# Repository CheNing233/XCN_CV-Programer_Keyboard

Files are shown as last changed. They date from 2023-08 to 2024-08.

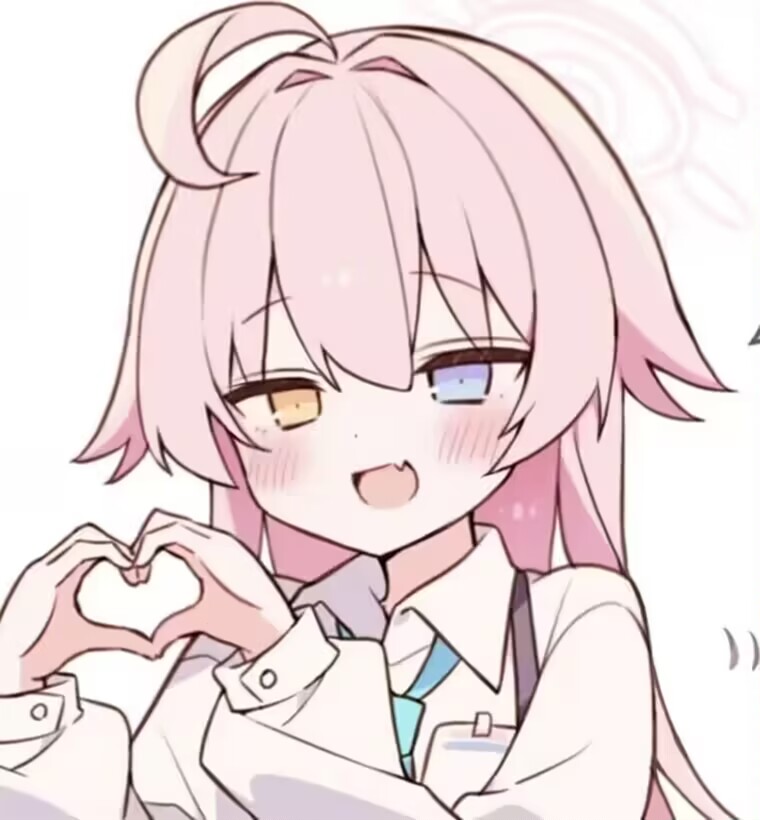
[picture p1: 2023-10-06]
HDK/PCB/QQ图片20231001015254.jpg

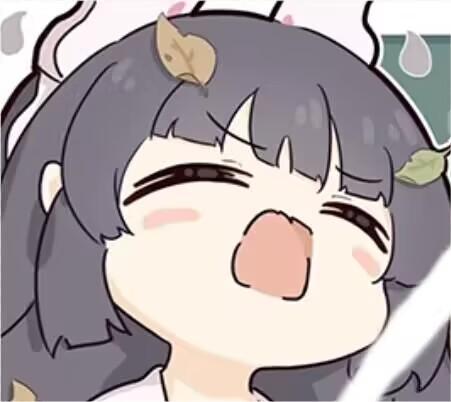
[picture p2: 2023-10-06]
HDK/PCB/QQ图片20231001020005.jpg

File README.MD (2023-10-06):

# XCN CV-Programer Keyboard (USB+BLE)

Dual mode 8-key keyboard based on CH573 microcontroller, Using an on chip integrated BLE wireless communication module and USB controller

一个`菜鸡`大学生的学习项目

## Feature

- [x] X, C, V, Space, Ctrl键
- [x] 旋转编码器(Encoder)设计的音量(Vol)滚轮以及播放暂停(Play/Pause)键
- [x] USB/BLE模式切换开关
- [ ] 光污染

## Progress & Tips

- [x] USB
- [x] BLE
- [x] Key scan
- [x] PCB
- [x] Casing CAD
- [ ] Macro
- [ ] ...

尝试使用补偿来解决BLE上传Encoder关于 “丢失数据” 的问题

## Thanks

- WCH南京沁恒
- You

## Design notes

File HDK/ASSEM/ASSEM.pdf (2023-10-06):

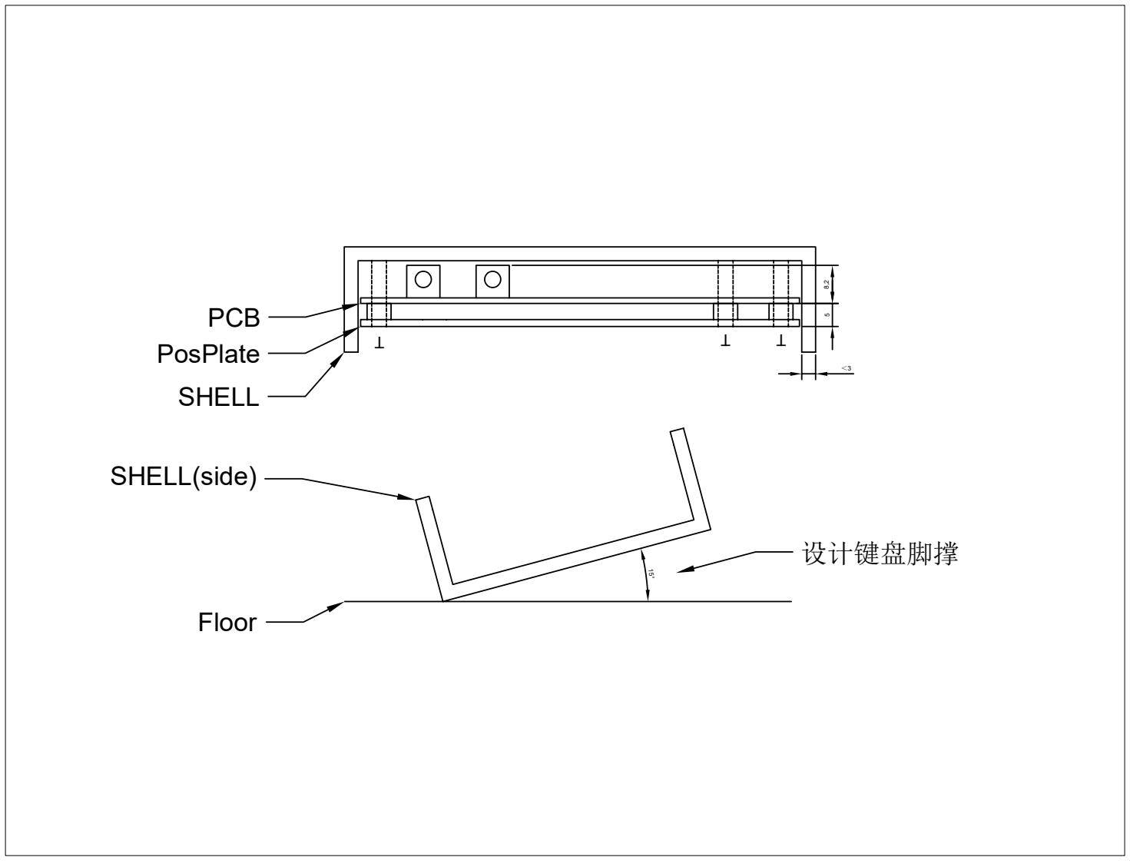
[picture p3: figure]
PCB PosPlate SHELL; T 15°Floor SHELL(side); 设计键盘脚撑

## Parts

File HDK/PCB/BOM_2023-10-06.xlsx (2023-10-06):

Designator | Value | Footprint | Device
C1 | 1uf | C0805 | CAP_0805 | 电容
C2 | 4.7uf | C0805 | CAP_0805
C3,C4,C5,C6 | 100nF | C0603 | CAP_0603
C7 | 0.1uf | C0805 | CAP_0805
D1 |  | SMA_L4.3-W2.6-LS5.2-RD | SS24_C50645 | 肖特基二极管
D2 |  | LL-34_L3.5-W1.5-RD | ZMM5V1_C707194 | 稳压二极管
H1,H2 |  | HDR-TH_2P-P2.54-V-F | HDR-F_2.54_1x2P
KEY1,KEY2,KEY3,KEY4,KEY5 |  | AxisSeat_14_18_XCN1 | CPG151101S11 | 轴座
L1 |  | ANT2051 | AN2051-245 | 陶瓷天线
LED1,LED2 |  | LED_0805 | LED_0805-G,LED_0805-R | 0805充电指示灯
M1 |  | VIBRATING-MOTOR-SMD_3P-C9900001680 | Z3OC1T8219731 | 振动电机
Q1,Q3 |  | SOT-23-3_L2.9-W1.3-P1.90-LS2.4-BR | FMMT718_C5277995 | FMMT低阻pnp三极管
Q2,Q4 |  | SOT-23-3_L2.9-W1.4-P1.90-LS2.6-BR | AO3401_C727156 | AO3401p沟道pmos
R1 | 2.2K | R0805 | Res_0805 | 电阻
R2,R9,R10,R12 | 10K | R0805 | Res_0805
R3 | 1K | R0805 | Res_0805
R4 | 100K | R0805 | Res_0805
R5,R6 | 5.1K | R0805 | Res_0805
R7 | 6.8K | R0805 | Res_0805
R8,R11 | 0K | R0805 | Res_0805
R13 | 2.4K | R0805 | Res_0805
SW1,SW6 |  | SW-TH_SK12D07VG3 | SK12D07VG3 | 拨动开关
SW2 |  | SW-SMD_L3.9-W3.0-P4.45 | TS-1088R-02026 | RST龟仔
SW3 |  | SW-TH_EC11XXXXXXXX | EC11E18244AU | EC11编码器
SW7,SW8 |  | KEY-TH_4P-L7.1-W5.0-P4.50-LS2.5 | TS-1093A-A3B2-D2 | 侧按钮
U1 |  | SOT-23-5_L3.0-W1.7-P0.95-LS2.8-BL | RT9013-33GB | LDO稳压
U2,U3,U4,U6,U7,U8 |  | LED-SMD_L3.2-W2.8-TR | SK6812MINI-E_C5149201 | 6812RGB灯珠
U5 |  | ESOP-8_L4.9-W3.9-P1.27-LS6.0-BL-EP | TP4056_C725790 | TP4056电池充电芯片
U9 |  | QFN-28_L4.0-W4.0-P0.40-BL-EP | CH573F | MCU
USB1 |  | USB-C-SMD_KH-TYPE-C-16P | KH-TYPE-C-16P-T | TYPEC
X1 | 32.768kHz | OSC-SMD_L3.2-W1.5 | X321532768KGD2SI | 32K时钟晶振
X2 | 32MHz | OSC-SMD_4P-L2.0-W1.6-BL | X201632MMB4SI | 32M主频晶振

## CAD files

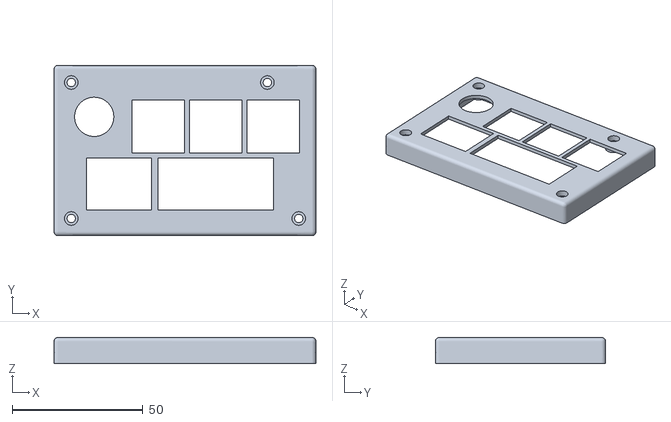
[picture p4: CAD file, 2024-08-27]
HDK/CASING/CasingUpper.stl
100.2 x 65.2 x 10.0

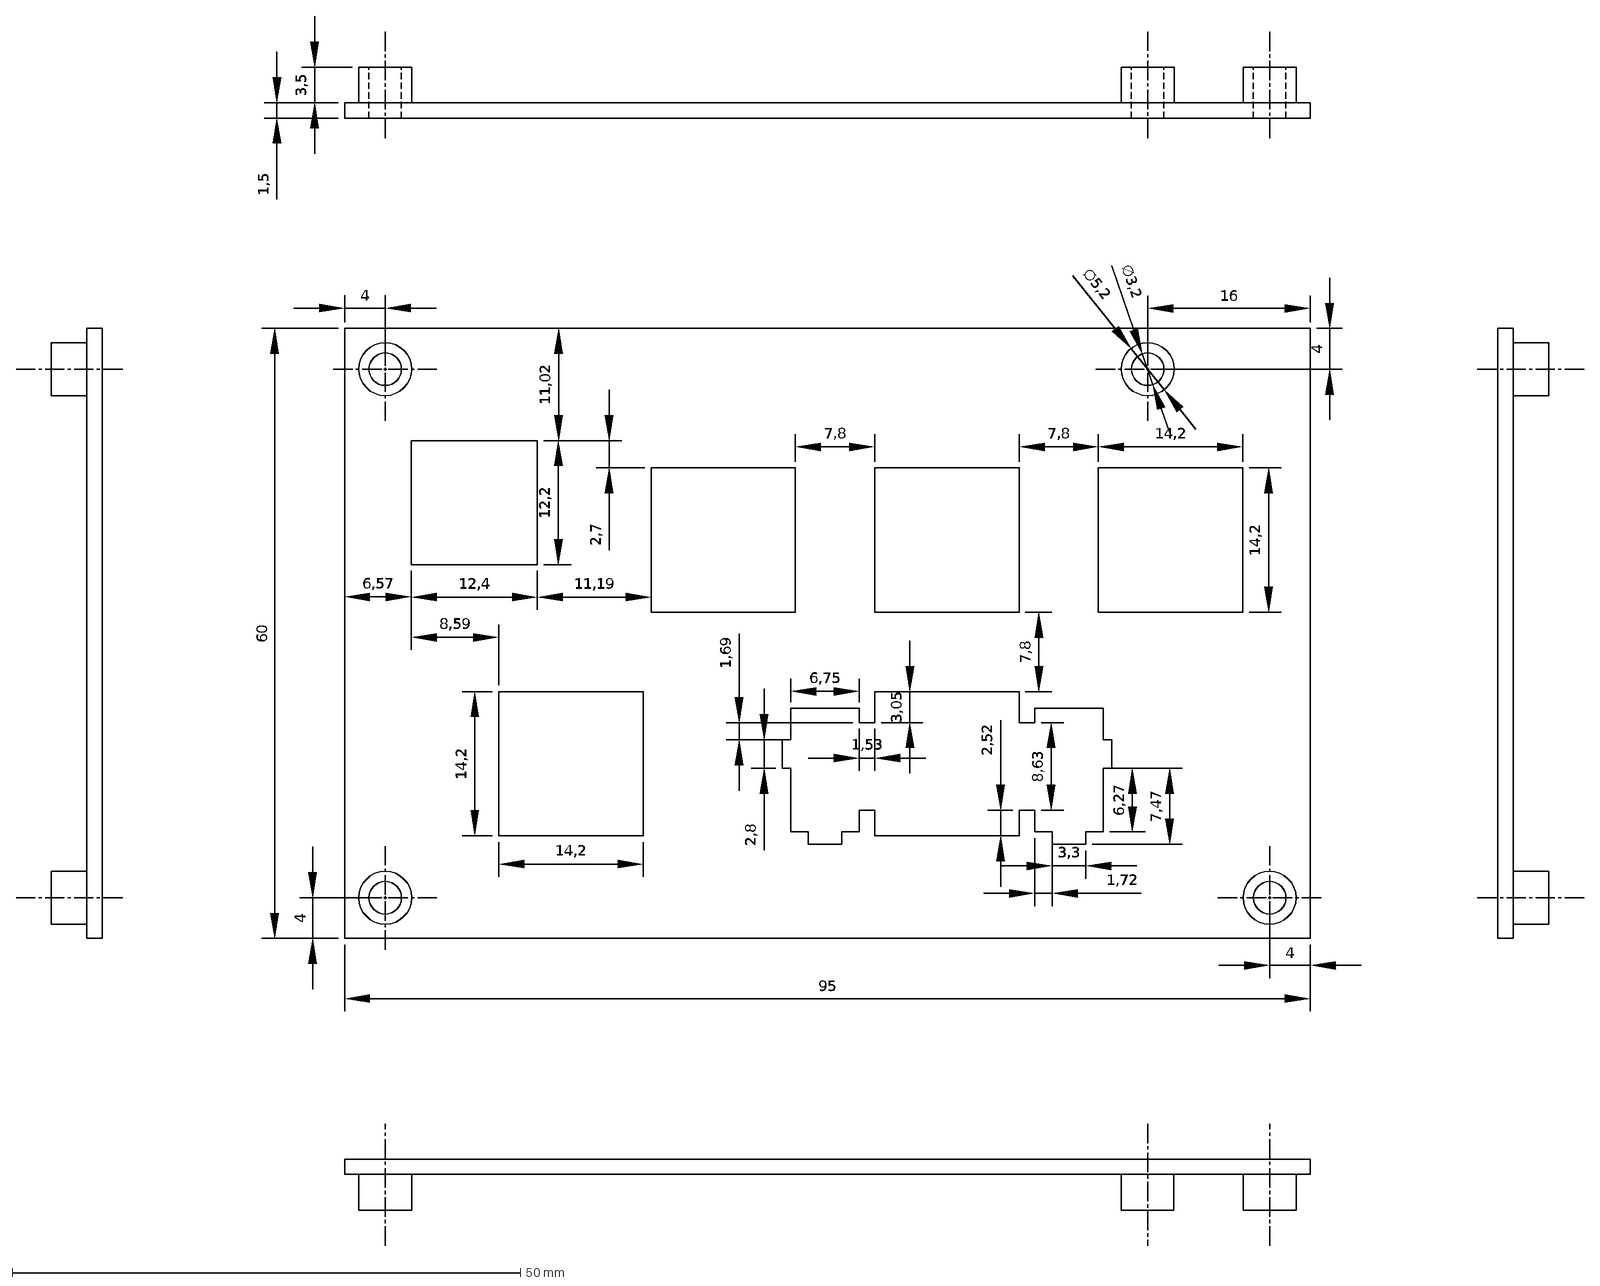
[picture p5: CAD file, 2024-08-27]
HDK/POS_PLATE/PosPlate.dxf
60
95
4
16
14,2
∅3,2
∅5,2
11,02
12,2
6,57
12,4
8,59
11,19
3,05
1,53
1,69
2,8
6,75
2,52
1,72
3,3
7,47
6,27
2,7
7,8
8,63
1,5
3,5

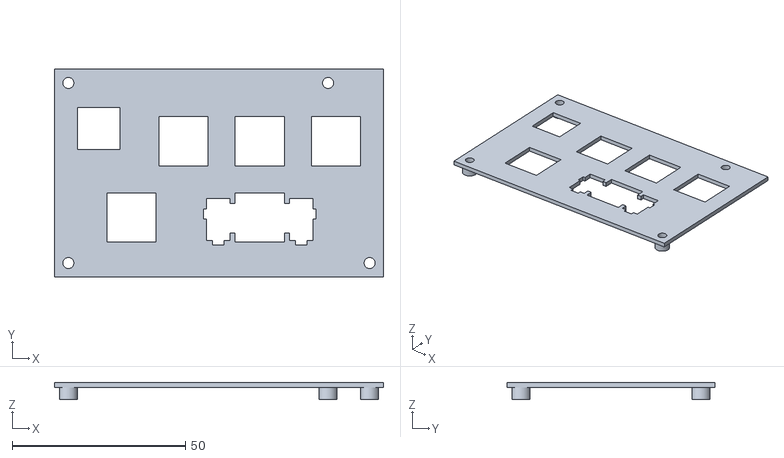
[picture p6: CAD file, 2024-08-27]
HDK/CASING/PosPlate.stl
95.0 x 60.0 x 5.00

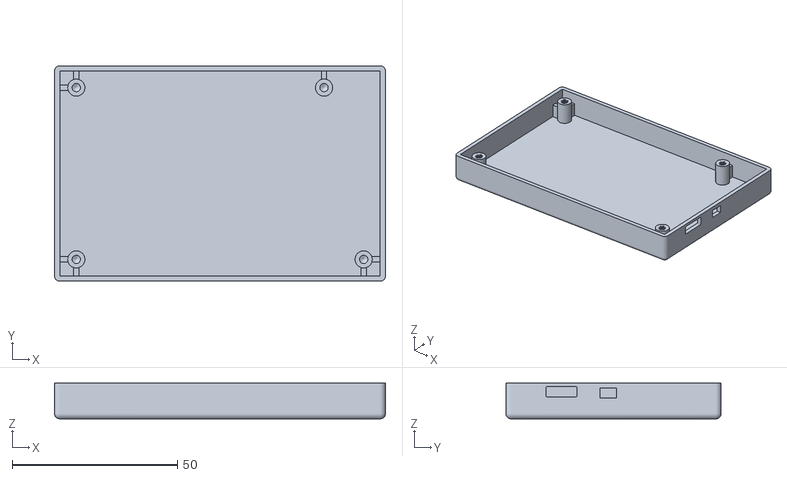
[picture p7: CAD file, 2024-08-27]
HDK/CASING/CasingBottom.stl
100.2 x 65.2 x 10.8

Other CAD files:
HDK/ASSEM/ASSEM.dwg
HDK/CASING_REF/CASING_REF.dwg
HDK/POS_PLATE/PosPlate_o.dwg
HDK/CASING/CASING_CAD.dxf
HDK/POS_PLATE/DMKB_01 v4.dwg
HDK/CASING/DMKB_02 v20.dwg
HDK/CASING/CASING_CAD.dwg
HDK/POS_PLATE/PosPlate.dwg

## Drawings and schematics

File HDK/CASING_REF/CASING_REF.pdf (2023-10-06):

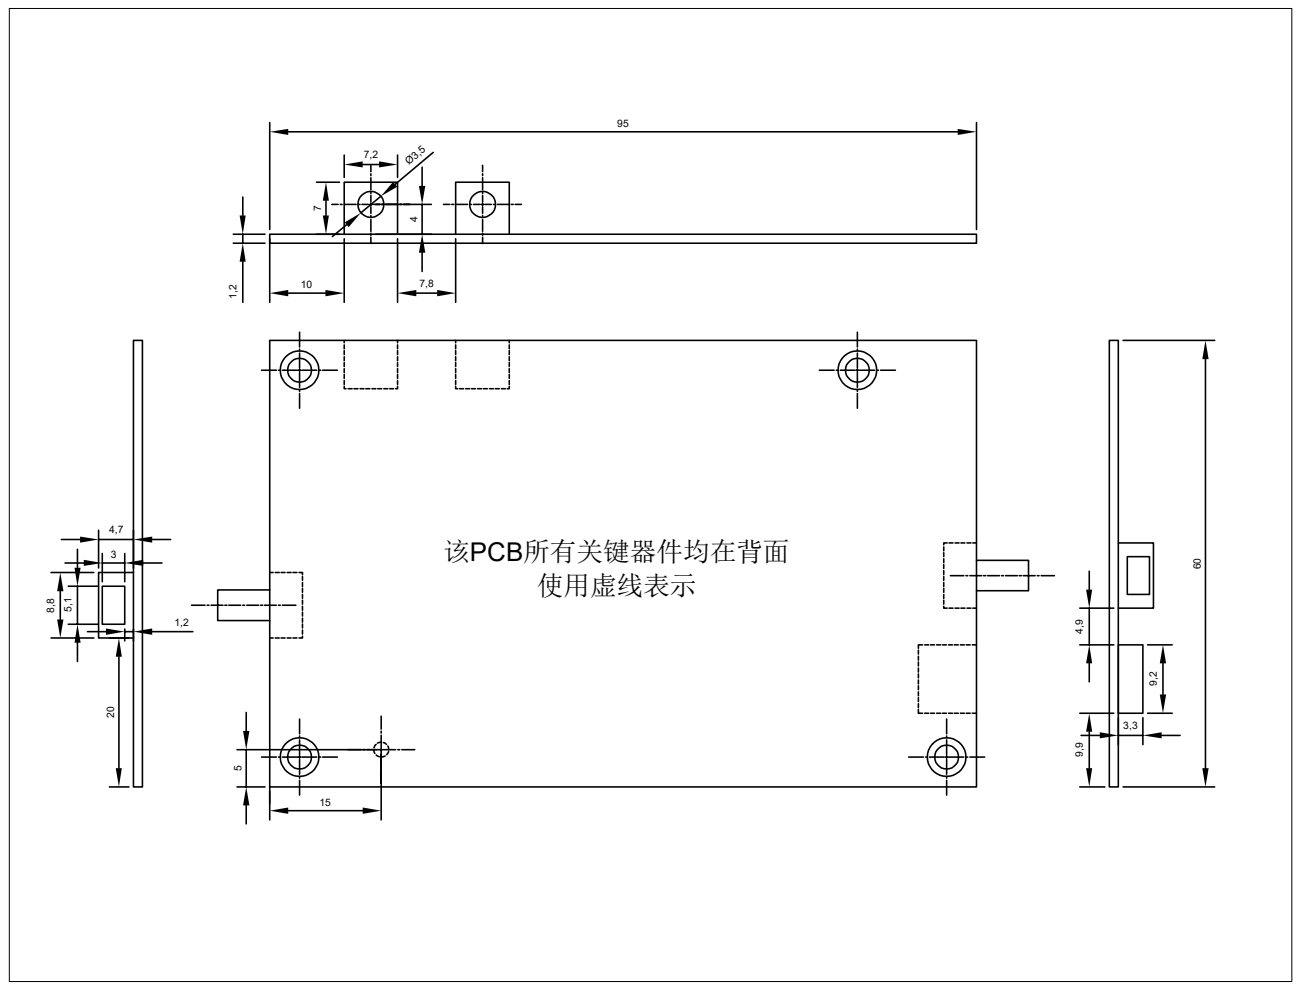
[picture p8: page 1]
该PCB所有关键器件均在背面 使用虚线表示 15 ⁵

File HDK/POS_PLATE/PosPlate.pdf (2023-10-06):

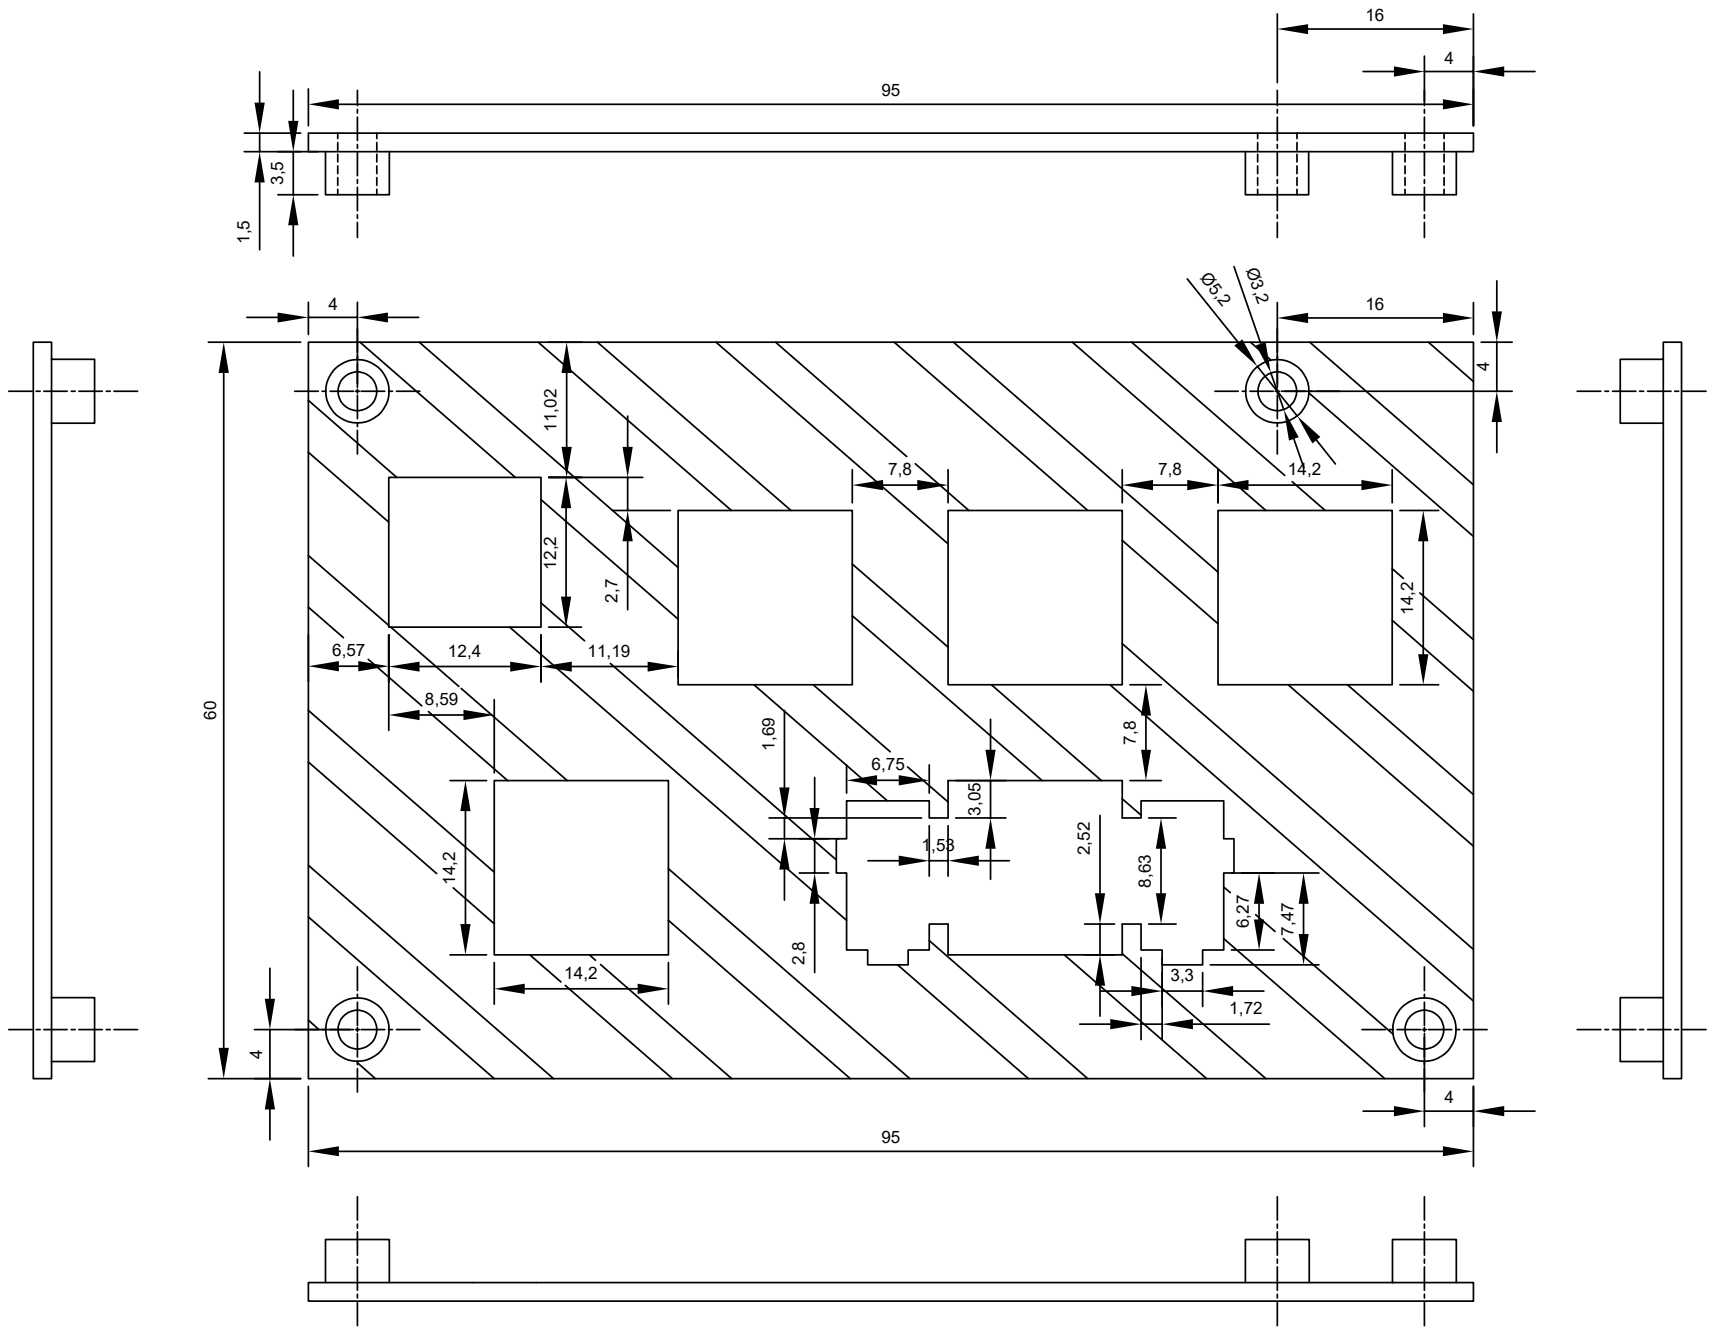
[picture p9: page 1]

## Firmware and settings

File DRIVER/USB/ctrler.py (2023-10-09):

import os
import logging
from array import array

import usb.core
import usb.util
import usb.backend.libusb1


class USB_Controller:
    pyusb_backend_path = ""
    pyusb_backend = None

    pyusb_device: usb.core.Device = None

    xcnkb_idVendor = 0x413D
    xcnkb_idProduct = 0x2107

    xcnkb_bulkin_addr = 0x83
    xcnkb_bulkout_addr = 0x4

    def __init__(self) -> None:
        self.pyusb_backend_path = os.path.join(
            os.path.dirname(os.path.abspath(__file__)), "libusb-1.0.dll"
        )

        self.pyusb_backend = usb.backend.libusb1.get_backend(
            find_library=lambda x: self.pyusb_backend_path
        )

        logging.info("pyusb.backend = %s" % (self.pyusb_backend))

    def get_target_device(self) -> int | None:
        self.pyusb_device = usb.core.find(
            idVendor=self.xcnkb_idVendor,
            idProduct=self.xcnkb_idProduct,
            backend=self.pyusb_backend,
        )

        if self.pyusb_device == None:
            logging.error("目标设备查找失败")
            return None

        # logging.debug("Target device info:\n%s" % (self.pyusb_device))

        self.pyusb_device.set_configuration()

        return self.pyusb_device.get_active_configuration()

    def check_valid(self) -> list | None:
        if self.pyusb_device == None:
            logging.error("设备句柄为空，停止该操作")
            return None

        msg = array("B")
        msg.append(0)

        logging.info("MSG = %s" % (msg))

        self.pyusb_device.write(self.xcnkb_bulkout_addr, msg, 3000)

        response = None

        try:
            response = self.pyusb_device.read(self.xcnkb_bulkin_addr, 64, 3000)
        except:
            logging.error("self.pyusb_device.read 失败")
            return None

        if not response[0] == 233:
            logging.error("self.pyusb_device.read 下位机响应异常")
            return None

        logging.info("MSG = %s" % (response))

        return [response[1], response[2], response[3]]

    def write(self, cmd_key, msg_data: array = None) -> array:
        if self.check_valid() == None:
            logging.error("操作取消")
            return None

        msg = array("B")
        msg.append(cmd_key)

        if msg_data:
            msg += msg_data
            logging.info(
                "即将向 0x%x 发送 %d 请求，附加数据 = %s"
                % (self.xcnkb_bulkout_addr, cmd_key, msg_data),
            )

        try:
            self.pyusb_device.write(self.xcnkb_bulkout_addr, msg, 3000)
        except:
            logging.error("self.pyusb_device.write 失败")
            return None

        logging.info("成功向 0x%x 发送 %d 请求" % (self.xcnkb_bulkout_addr, cmd_key))

        try:
            response = self.pyusb_device.read(self.xcnkb_bulkin_addr, 64, 3000)
        except:
            logging.error("self.pyusb_device.read 失败")
            return None

        logging.info("0x%x 返回 = %s" % (self.xcnkb_bulkin_addr, response))

        return response


if __name__ == "__main__":
    logging.basicConfig(
        format="[%(asctime)s|%(levelname)s] %(funcName)s : %(message)s",
        level=logging.DEBUG,
    )

    logging.info("LOG OK")

    ctrler = USB_Controller()

    ctrler.get_target_device()

    print(ctrler.check_valid())

    # print(pyu.pyusb_device.product)
    # print(type(pyu.pyusb_device))
    # print(pyu.pyusb_device.get_active_configuration())

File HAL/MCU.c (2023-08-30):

/********************************** (C) COPYRIGHT *******************************
 * File Name          : MCU.c
 * Author             : WCH
 * Version            : V1.2
 * Date               : 2022/01/18
 * Description        : 硬件任务处理函数及BLE和硬件初始化
 *********************************************************************************
 * Copyright (c) 2021 Nanjing Qinheng Microelectronics Co., Ltd.
 * Attention: This software (modified or not) and binary are used for 
 * microcontroller manufactured by Nanjing Qinheng Microelectronics.
 *******************************************************************************/

/******************************************************************************/
/* 头文件包含 */
#include "HAL.h"

tmosTaskID halTaskID;

/*******************************************************************************
 * @fn      Lib_Calibration_LSI
 *
 * @brief   内部32k校准
 *
 * @param   None.
 *
 * @return  None.
 */
void Lib_Calibration_LSI(void) {
    if (Calibration_LSI_FLASH() > 15) {
        Calibration_LSI_FLASH();
    }
    if (Calibration_LSI_RAM() > 15) {
        Calibration_LSI_RAM();
    }
    TMOS_Set32KTuneValue(Int32K_Tune_FLASH, Int32K_Tune_RAM);
}

#if(defined(BLE_SNV)) && (BLE_SNV == TRUE)
/*******************************************************************************
 * @fn      Lib_Read_Flash
 *
 * @brief   Callback function used for BLE lib.
 *
 * @param   addr - Read start address
 * @param   num - Number of units to read (unit: 4 bytes)
 * @param   pBuf - Buffer to store read data
 *
 * @return  None.
 */
uint32_t Lib_Read_Flash(uint32_t addr, uint32_t num, uint32_t *pBuf) {
    EEPROM_READ(addr, pBuf, num * 4);
    return 0;
}

/*******************************************************************************
 * @fn      Lib_Write_Flash
 *
 * @brief   Callback function used for BLE lib.
 *
 * @param   addr - Write start address
 * @param   num - Number of units to write (unit: 4 bytes)
 * @param   pBuf - Buffer with data to be written
 *
 * @return  None.
 */
uint32_t Lib_Write_Flash(uint32_t addr, uint32_t num, uint32_t *pBuf) {
    EEPROM_ERASE(addr, num * 4);
    EEPROM_WRITE(addr, pBuf, num * 4);
    return 0;
}
#endif

/*******************************************************************************
 * @fn      CH57X_BLEInit
 *
 * @brief   BLE 库初始化
 *
 * @param   None.
 *
 * @return  None.
 */
void CH57X_BLEInit(void) {
    uint8_t i;
    bleConfig_t cfg;
    if (tmos_memcmp(VER_LIB, VER_FILE, strlen(VER_FILE)) == FALSE) {
        PRINT("head file error...\n");
        while(1);
    }
    SysTick_Config(SysTick_LOAD_RELOAD_Msk);
    PFIC_DisableIRQ(SysTick_IRQn);

    tmos_memset(&cfg, 0, sizeof(bleConfig_t));
    cfg.MEMAddr = (uint32_t) MEM_BUF;
    cfg.MEMLen = (uint32_t) BLE_MEMHEAP_SIZE;
    cfg.BufMaxLen = (uint32_t) BLE_BUFF_MAX_LEN;
    cfg.BufNumber = (uint32_t) BLE_BUFF_NUM;
    cfg.TxNumEvent = (uint32_t) BLE_TX_NUM_EVENT;
    cfg.TxPower = (uint32_t) BLE_TX_POWER;
#if(defined(BLE_SNV)) && (BLE_SNV == TRUE)
    cfg.SNVAddr = (uint32_t) BLE_SNV_ADDR;
    cfg.readFlashCB = Lib_Read_Flash;
    cfg.writeFlashCB = Lib_Write_Flash;
#endif
#if(CLK_OSC32K)
    cfg.SelRTCClock = (uint32_t) CLK_OSC32K;
#endif
    cfg.ConnectNumber = (PERIPHERAL_MAX_CONNECTION & 3)
            | (CENTRAL_MAX_CONNECTION << 2);
    cfg.srandCB = SYS_GetSysTickCnt;
#if(defined TEM_SAMPLE) && (TEM_SAMPLE == TRUE)
    cfg.tsCB = HAL_GetInterTempValue; // 根据温度变化校准RF和内部RC( 大于7摄氏度 )
#if(CLK_OSC32K)
    cfg.rcCB = Lib_Calibration_LSI; // 内部32K时钟校准
#endif
#endif
#if(defined(HAL_SLEEP)) && (HAL_SLEEP == TRUE)
    cfg.WakeUpTime = WAKE_UP_RTC_MAX_TIME;
    cfg.sleepCB = CH57X_LowPower; // 启用睡眠
#endif
#if(defined(BLE_MAC)) && (BLE_MAC == TRUE)
    for(i = 0; i < 6; i++)
    {
        cfg.MacAddr[i] = MacAddr[5 - i];
    }
#else
    {
        uint8_t MacAddr[6];
        GetMACAddress(MacAddr);
        for (i = 0; i < 6; i++) {
            cfg.MacAddr[i] = MacAddr[i]; // 使用芯片mac地址
        }
    }
#endif
    if (!cfg.MEMAddr || cfg.MEMLen < 4 * 1024) {
        while(1);
    }
    i = BLE_LibInit(&cfg);
    if (i) {
        PRINT("LIB init error code: %x ...\n", i);
        while(1);
    }
}

/*******************************************************************************
 * @fn      HAL_ProcessEvent
 *
 * @brief   硬件层事务处理
 *
 * @param   task_id - The TMOS assigned task ID.
 * @param   events  - events to process.  This is a bit map and can
 *                      contain more than one event.
 *
 * @return  events.
 */
tmosEvents HAL_ProcessEvent(tmosTaskID task_id, tmosEvents events) {
    uint8_t *msgPtr;

    if (events & SYS_EVENT_MSG) { // 处理HAL层消息，调用tmos_msg_receive读取消息，处理完成后删除消息。
        msgPtr = tmos_msg_receive(task_id);
        if (msgPtr) {
            /* De-allocate */
            tmos_msg_deallocate(msgPtr);
        }
        return events ^ SYS_EVENT_MSG;
    }
    if (events & LED_BLINK_EVENT) {
#if(defined HAL_LED) && (HAL_LED == TRUE)
        HalLedUpdate();
#endif // HAL_LED
        return events ^ LED_BLINK_EVENT;
    }
    if (events & HAL_KEY_EVENT) {
#if(defined HAL_KEY) && (HAL_KEY == TRUE)
        HAL_KeyPoll(); /* Check for keys */
        tmos_start_task(halTaskID, HAL_KEY_EVENT, MS1_TO_SYSTEM_TIME(100));
        return events ^ HAL_KEY_EVENT;
#endif
    }
    if (events & HAL_REG_INIT_EVENT) {
#if(defined BLE_CALIBRATION_ENABLE) && (BLE_CALIBRATION_ENABLE == TRUE) // 校准任务，单次校准耗时小于10ms
        BLE_RegInit();                                                  // 校准RF
#if(CLK_OSC32K)
        Lib_Calibration_LSI(); // 校准内部RC
#endif
        tmos_start_task(halTaskID, HAL_REG_INIT_EVENT,
                MS1_TO_SYSTEM_TIME(BLE_CALIBRATION_PERIOD));
        return events ^ HAL_REG_INIT_EVENT;
#endif
    }
    if (events & HAL_TEST_EVENT) {
        PRINT("* \n");
        tmos_start_task(halTaskID, HAL_TEST_EVENT, MS1_TO_SYSTEM_TIME(1000));
        return events ^ HAL_TEST_EVENT;
    }
    return 0;
}

/*******************************************************************************
 * @fn      HAL_Init
 *
 * @brief   硬件初始化
 *
 * @param   None.
 *
 * @return  None.
 */
void HAL_Init() {
    halTaskID = TMOS_ProcessEventRegister(HAL_ProcessEvent);
    HAL_TimeInit();
#if(defined HAL_SLEEP) && (HAL_SLEEP == TRUE)
    HAL_SleepInit();
#endif
#if(defined HAL_LED) && (HAL_LED == TRUE)
    HAL_LedInit();
#endif
#if(defined HAL_KEY) && (HAL_KEY == TRUE)
    HAL_KeyInit();
#endif
#if(defined BLE_CALIBRATION_ENABLE) && (BLE_CALIBRATION_ENABLE == TRUE)
    tmos_start_task(halTaskID, HAL_REG_INIT_EVENT,
            MS1_TO_SYSTEM_TIME(BLE_CALIBRATION_PERIOD)); // 添加校准任务，单次校准耗时小于10ms
#endif
    //  tmos_start_task( halTaskID, HAL_TEST_EVENT, 1600 );    // 添加一个测试任务
}
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

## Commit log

2023-10-06 完成基础功能
    [ASSEM.dwg, BOM_2023-10-06.xlsx, PosPlate.dwg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]
2023-10-06 FIX NAME
    [CASING_REF.dwg]
2023-10-07 优化BLE处Encoder
2023-10-09 完善改键功能
